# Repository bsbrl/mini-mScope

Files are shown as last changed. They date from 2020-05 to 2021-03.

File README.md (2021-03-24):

<p align="center">
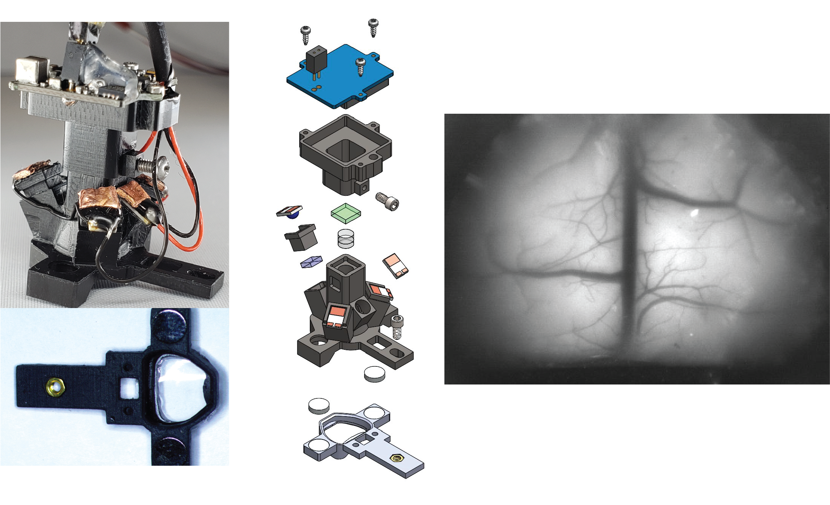
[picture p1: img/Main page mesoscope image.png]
  
</p>

Whole-cortex imaging in freely behaving mice using a head-mounted miniaturized microscope (mini-mScope). CMOS sensor sourced from the [Miniscope](https://github.com/Aharoni-Lab/Miniscope-v4/wiki).

The current version of the mini-mScope meets several experimental conditions highlighted below.

* Access to ~8x10 mm field of view of the mouse dorsal cortex
* Resolution ranges from ~39-56 micrometers across the field of view
* Weighs less than 15% of the mouse body weight (3.8 grams)
* Uniformly illuminates ~75% of the dorsal cortex with blue excitation light
* Green reflectance channel allows for hemodynamic correction ~65% of the field of view
* Does not impede mouse natural behavior (>1 hour mounting time with minimal effects on mouse traversed distance or speed)
* Posterior tail screw minimizes motion artifacts during vigorous, natural mouse behavior and during complex tasks, such as social interaction

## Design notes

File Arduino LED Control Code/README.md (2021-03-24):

Nested folders with the non-blocking functions used to alternately pulse the blue/green LEDs used for calcium/reflectance imaging.

We have also included code used for the sensory stimulus experiments performed on both anesthetized and freely moving mice

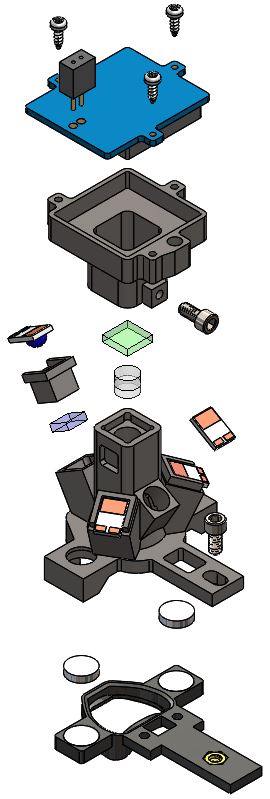
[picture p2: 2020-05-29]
Mesoscope CAD Files/Mesoscope Exploded View.JPG

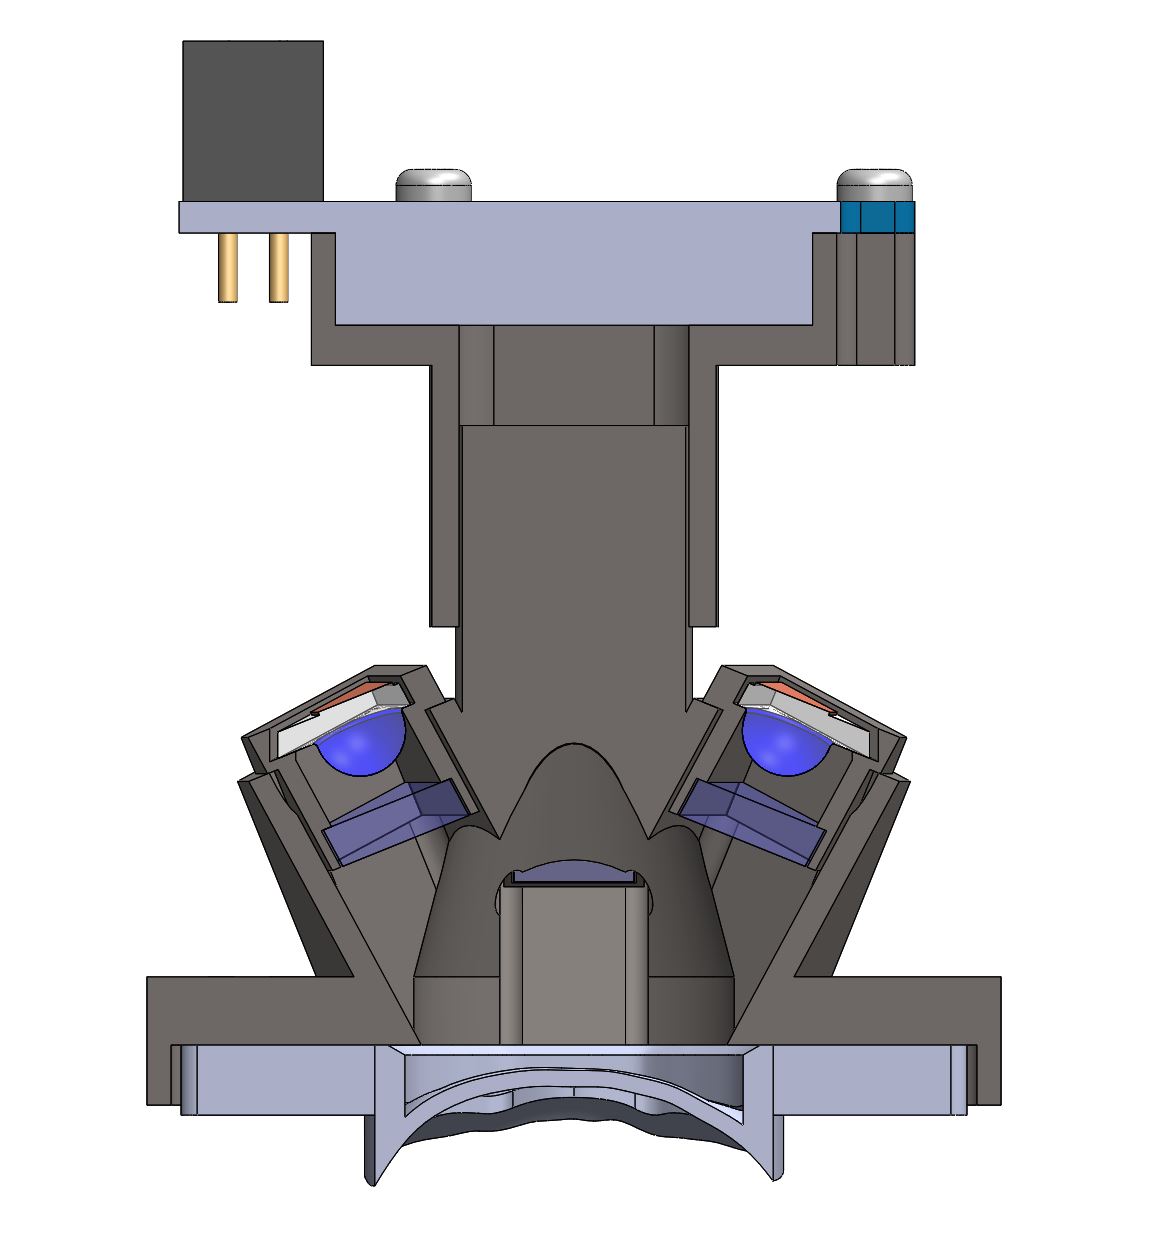
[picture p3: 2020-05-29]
Mesoscope CAD Files/Mesoscope Cross Section 2.JPG

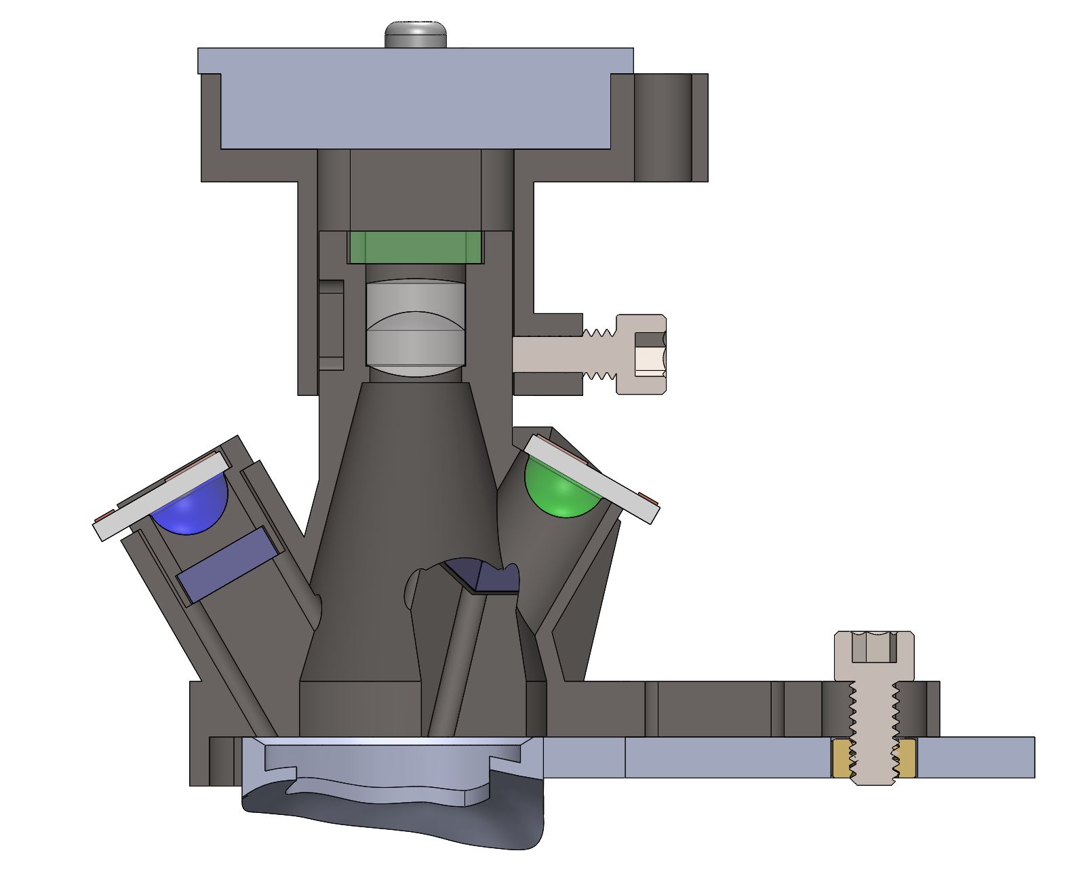
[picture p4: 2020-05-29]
Mesoscope CAD Files/Mesoscope Cross Section 1.JPG

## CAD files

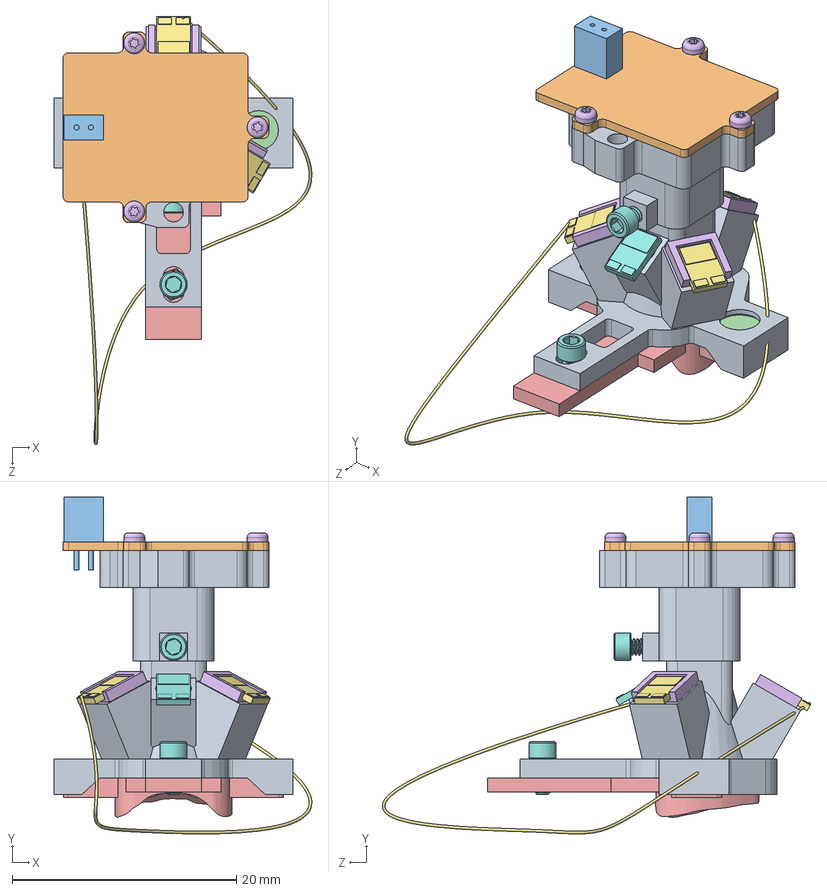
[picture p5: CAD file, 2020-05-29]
Mesoscope CAD Files/Mesoscope Assembly.SLDASM
23.0 x 30.0 x 38.2 mm
meso4.27_bottom_delrin
emmission_filter_4x4x1mm
excitation_filter_3x3x1mm x 3
filter_cube_ver5 x 3
excitation_led_rebel_blue_470nm x 3
excitation_led_rebel_green_530nm
meso4.22_top_delrin
CMOS_Imaging_Sensor_PCB
Pin Header Female
magnet x 4
082019_mesoscope_frame
thread_forming_screw x 3
92196A052_18-8 STAINLESS STEEL SOCKET HEAD CAP SCREW x 2
92736A001_BRASS HEX NUT

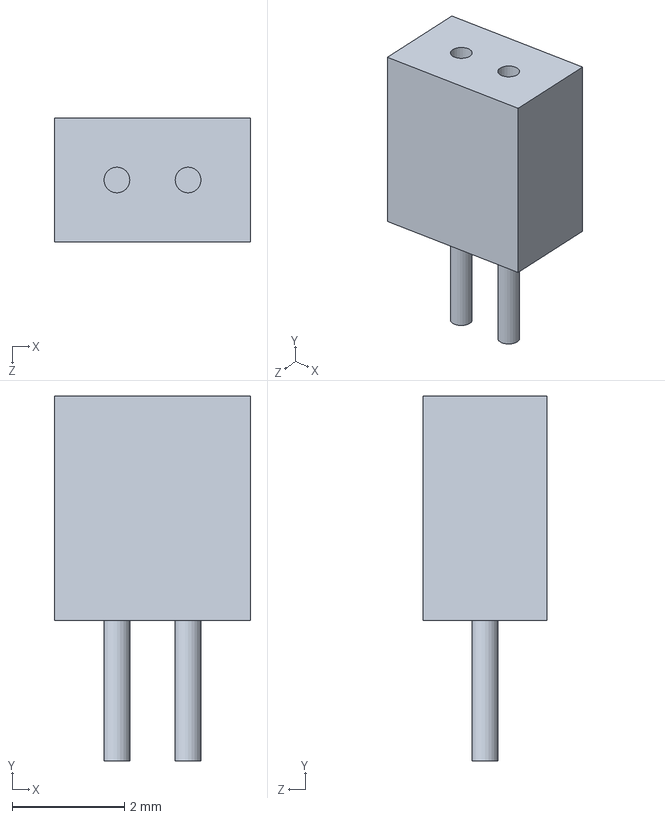
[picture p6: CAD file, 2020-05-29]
Mesoscope CAD Files/Pin Header Female.SLDPRT
3.50 x 6.51 x 2.21 mm

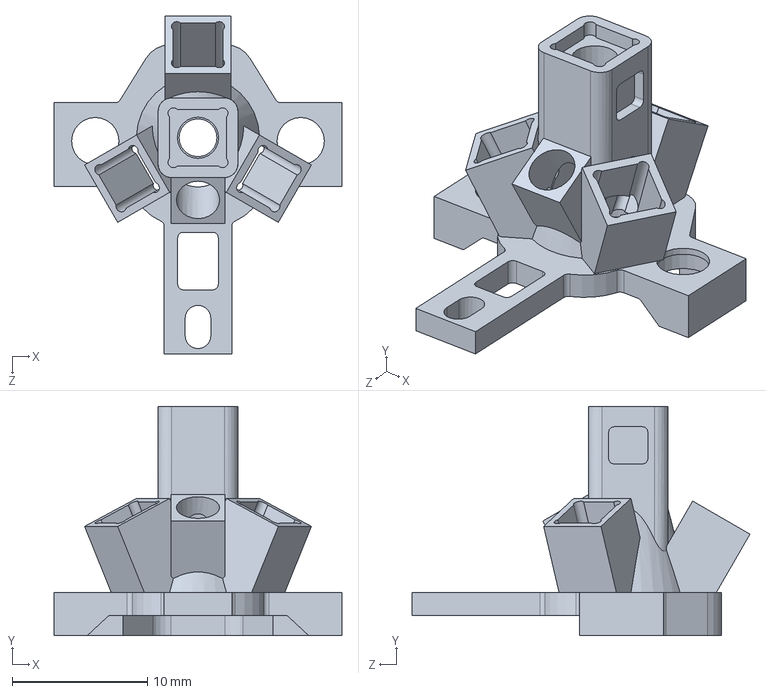
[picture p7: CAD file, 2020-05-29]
Mesoscope CAD Files/meso4.27_bottom_delrin.SLDPRT
21.3 x 17.0 x 25.0 mm

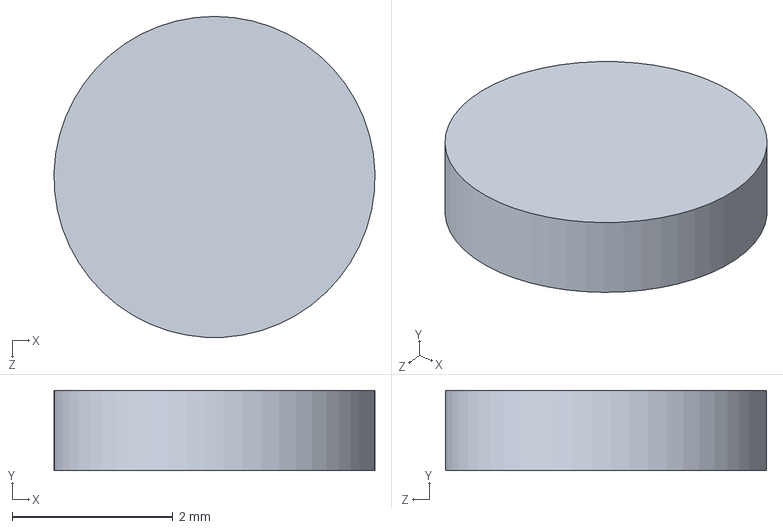
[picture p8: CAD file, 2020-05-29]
Mesoscope CAD Files/magnet.SLDPRT
4.00 x 1.00 x 4.00 mm

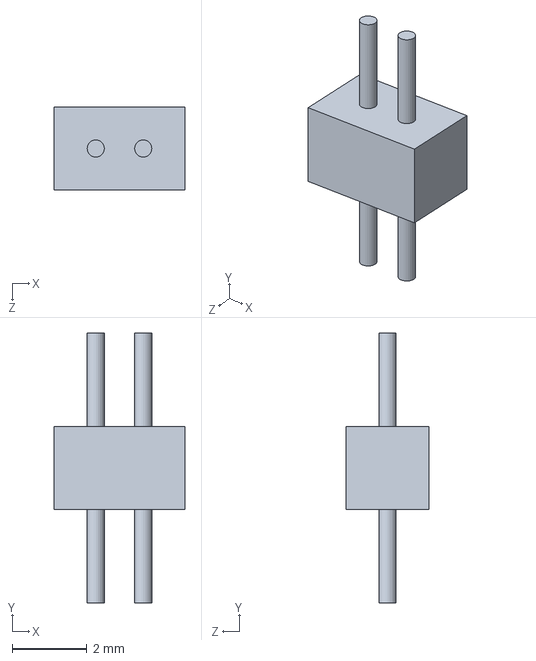
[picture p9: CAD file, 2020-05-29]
Mesoscope CAD Files/Pin Header male.SLDPRT
3.50 x 7.23 x 2.21 mm

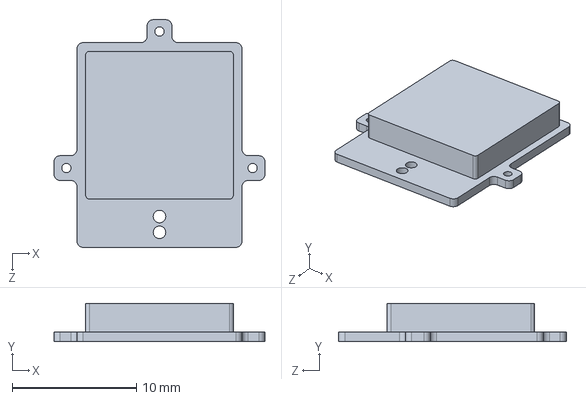
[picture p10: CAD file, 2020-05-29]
Mesoscope CAD Files/CMOS_Imaging_Sensor_PCB.SLDPRT
17.0 x 3.09 x 18.4 mm

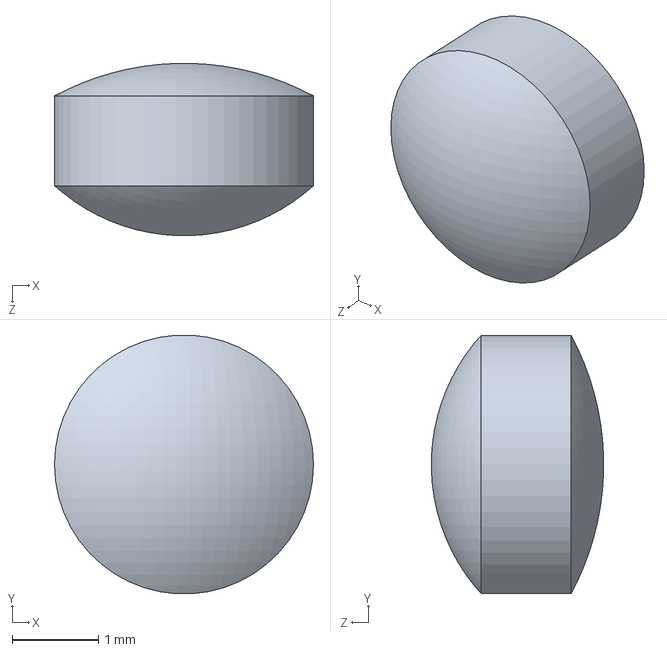
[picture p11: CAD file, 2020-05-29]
Mesoscope CAD Files/NONE (1).sldprt
3.00 x 2.99 x 1.99 mm

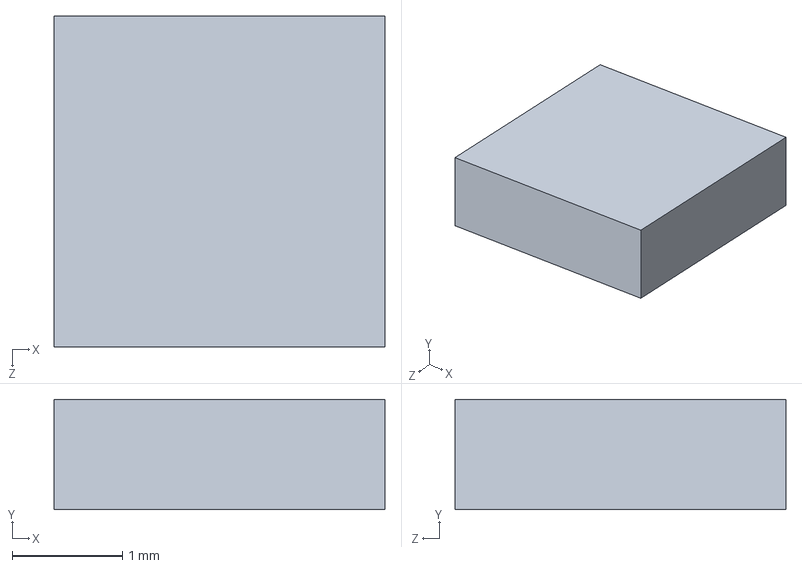
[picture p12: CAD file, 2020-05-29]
Mesoscope CAD Files/excitation_filter_3x3x1mm.SLDPRT
3.00 x 1.00 x 3.00 mm

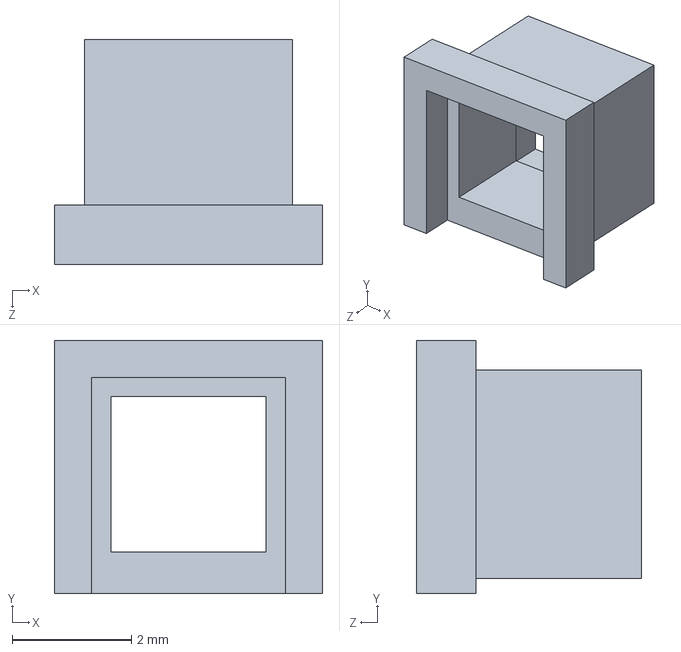
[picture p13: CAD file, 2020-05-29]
Mesoscope CAD Files/filter_cube_ver5.SLDPRT
4.50 x 4.25 x 3.78 mm

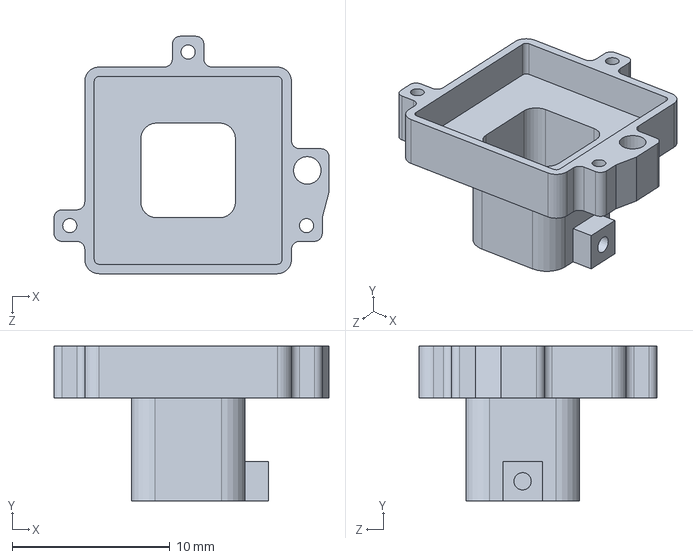
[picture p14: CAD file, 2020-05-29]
Mesoscope CAD Files/meso4.22_top_delrin.SLDPRT
17.4 x 9.82 x 15.1 mm

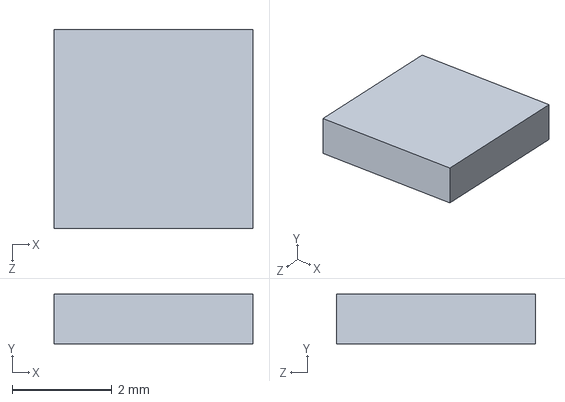
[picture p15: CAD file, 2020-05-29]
Mesoscope CAD Files/emmission_filter_4x4x1mm.SLDPRT
4.00 x 1.00 x 4.00 mm

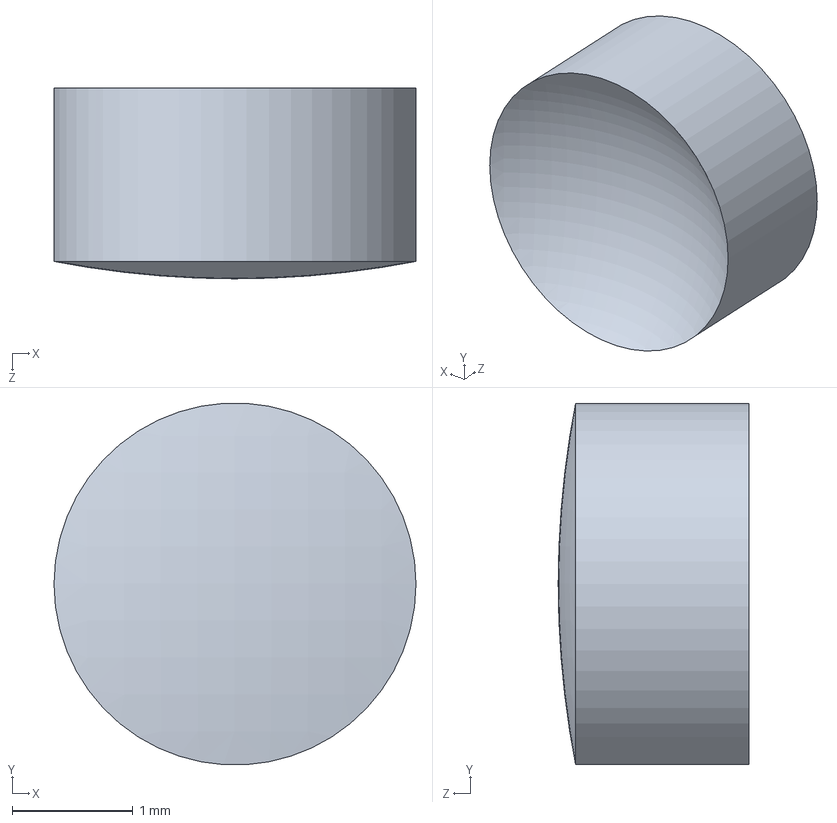
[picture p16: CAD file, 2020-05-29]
Mesoscope CAD Files/NONE_2 (2).sldprt
3.00 x 2.99 x 1.58 mm

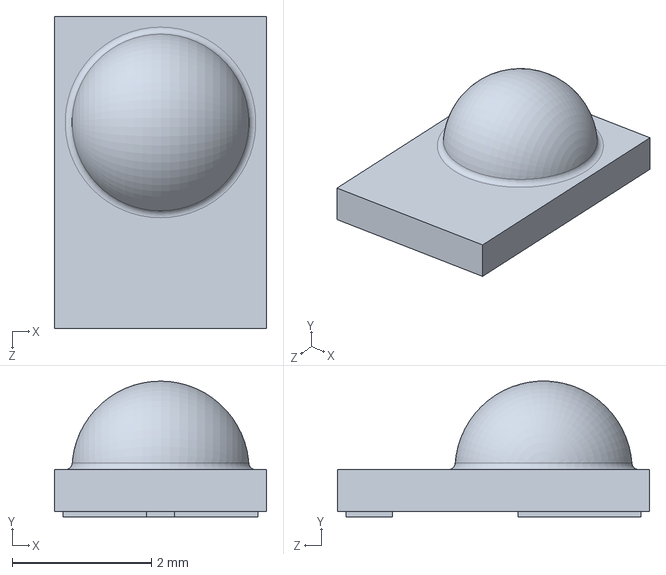
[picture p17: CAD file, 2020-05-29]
Mesoscope CAD Files/excitation_led_rebel_green_530nm.SLDPRT
3.05 x 1.95 x 4.49 mm

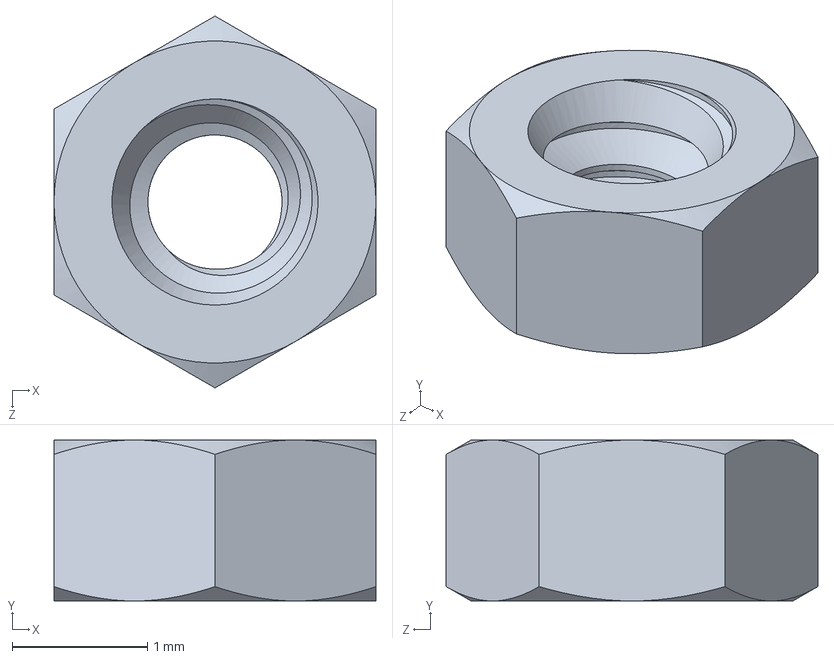
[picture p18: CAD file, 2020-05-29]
Mesoscope CAD Files/92736A001_BRASS HEX NUT.SLDPRT
2.38 x 1.19 x 2.75 mm

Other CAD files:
Mesoscope CAD Files/excitation_led_rebel_blue_470nm.SLDPRT
Mesoscope CAD Files/082019_mesoscope_frame.SLDPRT
Mesoscope CAD Files/thread_forming_screw.SLDPRT
Mesoscope CAD Files/92196A052_18-8 STAINLESS STEEL SOCKET HEAD CAP SCREW.SLDPRT

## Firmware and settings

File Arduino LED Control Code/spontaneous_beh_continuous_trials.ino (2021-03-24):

//-------------------------------User Defined Variables-------------------------------------------------------------------------------------------
const double blueled_time = 20; //led blinking interval in ms
const double greenled_time = 20; // green led blinking interval in ms
int totaltrials = 1; //total trials to run for specified experiment time
float exptime = 200; //data collection segment in seconds
float led_warmup_time = 120; //experimentally determined led warm up period in seconds

//notes
//1. LED pulse times have to be at least ~5ms less than the framerate set on the Miniscope camera (CMOS actual framerate may vary by +- ~5ms from set framerate)
//2. LED warmup time will add to the total experiment time for the first trial if there are more than 1 total trials set. This means if the experiment
//time is set 10 seconds per trial for 3 total trials, LED warmup time will run 120sec first before the first trial of 10 seconds. Then each subsequent
//trial will only last for the desired 10 seconds.
//3. For long experiment collection sections, you can simply change the total trials to 1 trial and set the experiment time to something less than 200 seconds
//as the total experiment time (LED warmup + exp_time*totaltrials) should be less than 350-400 seconds total to prevent LED  burnout.
//4. Note that at the end of each trial, the software will continue to record video so the LEDs maintain a constant temperature. The serial monitor
//will print the time at the end of each trial and these times can be passed to a script we can provide to auto-segment the video
//into individual trials if more than one trial duration has been set above



//-------------------------------Main Variables-------------------------------------------------------------------------------------------------------

const byte triggerin = 7; //trigger from controller to DAQ to start videos
const byte triggerout = 8; //ttl pulse from DAQ to controller when a frame is taken
const byte macroscope_trig = 2; //trig for external macroscope
unsigned long duration;

float globaltime;
float globaltime2;
float starttime;
float starttime2;
float previousMillis = 0; // will store last time LED was updated
float previousMillis2 = 0; // store last time buzzstim was updated


int count = 1;
int count2 = 1;
int totalloop = 1; // how many times to run through each stimulus pair
int incomingByte = 0;   // for incoming serial data

int testvar = 0;
const byte blueled = 3; // blue led at pin 3
const byte greenled = 10; // green led at pin 10


float ledtime; //time to turn on led before next trial starts (sec)

int ledState = HIGH;
int ledState2 = HIGH;
int pulsecount = 1;
int greencount = 1;
int bluecount = 1;
int buzzcount = 1;


float pulse_time = 5; //when to start pulse in seconds
float pulse_duration = 1; //pulse duration for stimulus in seconds
float pausetime = 0; //pause time between trials in seconds
float var;

float exptime_change = exptime;
float pulse_timechange = pulse_time;
//int trigdelay = 1;

int usercount = 1;
int val = 0;
int first_trigval = 0;
int blue_ledval = 0;
int green_ledval = 0;
int j;
int triggerwrite = 1;
int statementcount = 1;
int led_warmup_count = 1;
float temptime;


unsigned long temp;
unsigned long temp2;

volatile byte state = LOW;

void setup() {
  // put your setup code here, to run once:
  pinMode(triggerin, OUTPUT);
  pinMode(triggerout, INPUT);
  pinMode(blueled, OUTPUT);
  pinMode(greenled, OUTPUT);
  pinMode(macroscope_trig, OUTPUT);
  attachInterrupt(digitalPinToInterrupt(triggerout), PulseLed, CHANGE);
  Serial.begin(19200);

  //Serial.println("Enter any key to begin the program");
}

void loop() {
  if (testvar == 0) {
    incomingByte = Serial.read();
    usercount += 1;
    if (usercount % 100000 == 0) {
      Serial.println("Pending user input... enter y to begin ");
      //Serial.println(interval*1000);
    }

    if (incomingByte != -1) { //if user input is non zero
      testvar = 1;
      //Serial.println(usercount);
    }
  }


  if (testvar == 1) {
    if (totalloop <= totaltrials) {
      starttime2 = micros();
      if (triggerwrite == 1) {
        digitalWrite(triggerin, HIGH); // trigger DAQ to start recording

        triggerwrite = 2;
      }

      if (count == 1) { // take first instance after trigger sent and record this ttl value
        first_trigval = state;
        count = 2;
      }

      if (count == 2) {
        if (state != first_trigval) { //take first instance where the ttl pulse value changes
          Serial.println(" ");
          Serial.println("Starting video now: ");
          Serial.println(" ");

          globaltime = micros(); // take teensy clock
          starttime = globaltime;
          globaltime2 = globaltime;
          count = 3;
          //Serial.print("current val ");
          //Serial.print(val);
          //Serial.println(" ");
          blue_ledval = state; //assign first different value to be blue led (assume first bright frame captured to be blue led)
          green_ledval = first_trigval; //assign 0 state ttl pulse to be green led

          //Serial.println(blue_ledval);
          //Serial.println(green_ledval);
        }
      }
      if (totalloop == 1) {
        pulse_timechange = pulse_time + led_warmup_time;
        exptime_change = exptime + led_warmup_time;
      }

      if (count == 3) {
        if (starttime <= (exptime_change + globaltime / 1000000) * 1000000) { //run led pulsing for experiment duration
          if (led_warmup_count == 1) {
            if (starttime >= (led_warmup_time + globaltime / 1000000) * 1000000) {
              //digitalWrite(macroscope_trig,HIGH);
              Serial.print("LEDs warmed up");
              Serial.println(" ");
              Serial.print("Current time is ");
              if (totalloop == 1) {
                temptime = (starttime - globaltime) / 1000;
              } else {
                temptime = (starttime - globaltime2) / 1000;
              }

              Serial.print(temptime);
              Serial.println(" milliseconds");
              Serial.println(" ");
              led_warmup_count = 2;
            }
          }
          float currentMillis = micros();
          starttime = currentMillis;
          statementcount = 1;
          if (blue_ledval == state) { //if blue led ttl is equal to current read ttl value

            if (bluecount == 1) { // if "on" counter for blue led is true
              previousMillis = currentMillis;
              digitalWrite(blueled, HIGH); //turn blue led on
              digitalWrite(macroscope_trig, HIGH);
              //ledState = LOW;//switch led state
              bluecount = 2; //change counter to "off" for blueu led
            }
            if (currentMillis - previousMillis >= blueled_time * 1000) { //if time grows beyond desired for blue led pulse
              digitalWrite(blueled, LOW); //turn led off
              digitalWrite(macroscope_trig, LOW);
              greencount = 1; //assume a switch to green led now
              //ledState2 = HIGH;
            }
          } else { //run when ttl value changes (i.e. switch from green to blue)

            if (greencount == 1) {

              previousMillis = currentMillis; //repeat above with green led
              digitalWrite(greenled, HIGH);
              digitalWrite(macroscope_trig, HIGH);
              //ledState2 = LOW;
              greencount = 2;

            }
            if (currentMillis - previousMillis >= blueled_time * 1000) {
              digitalWrite(greenled, LOW);
              digitalWrite(macroscope_trig, LOW);
              bluecount = 1;
              //ledState = HIGH;
            }
          }
        } else {
          //            for (j=1;j<=1000;j++){
          //              digitalWrite(triggerin,LOW);
          //            }

          //digitalWrite(triggerin,LOW);
          if (statementcount == 1) {
            Serial.print("End of Trial ");
            Serial.println(totalloop);
            Serial.print("Current time is ");
            if (totalloop == 1) {
              temptime = (starttime - globaltime) / 1000;
            } else {
              temptime = (starttime - globaltime2) / 1000;
            }
            Serial.print(temptime);
            Serial.println(" milliseconds");
            Serial.println(" ");
            //digitalWrite(greenled,LOW);
            //digitalWrite(blueled,LOW);
            statementcount = 2;
          }


          if (starttime <= (exptime_change + pausetime + globaltime / 1000000) * 1000000) {
            starttime = micros();
          } else {
            if (count2 == 1) {
              starttime2 = micros();
              count2 = 2;
              ledtime = starttime2 + 0;//10000;
            }
            if ( starttime <= ledtime ) {
              starttime = micros();
            } else {
              //digitalWrite(ledpin,LOW);
              starttime = micros();
              exptime_change = starttime / 1000000 + exptime;
              pulse_timechange = starttime / 1000000 + pulse_time;
              globaltime = 0;


              totalloop += 1;
              triggerwrite = 1;
              count2 = 1;
            }
            //              starttime = micros();
            //              exptime_change = starttime/1000000 + exptime;
            //              pulse_timechange = starttime/1000000 + pulse_time;
            globaltime = 0;
            starttime = micros();
            //
            //
            //              totalloop += 1;
            //              triggerwrite = 1;
          }

        }
      }
    } else { //if outside experiment time
      if (totalloop == totaltrials + 1) {
        Serial.println("Experiment has concluded");
        digitalWrite(blueled, LOW); //shut down leds and conclude experiment
        digitalWrite(greenled, LOW);
        digitalWrite(triggerin, LOW);
        digitalWrite(macroscope_trig, LOW);
        totalloop += 1;
        testvar = 2;
      }
    }
  }
}



void PulseLed() {
  state = digitalRead(triggerout);
  digitalWrite(macroscope_trig, LOW);
  //delayMicroseconds(2000);
}

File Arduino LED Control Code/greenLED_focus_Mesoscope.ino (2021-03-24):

int i=0;
char buf[3];
int ledpin = 9;

void setup()
{
   Serial.begin(19200);
   pinMode(ledpin,OUTPUT);
}

void loop()
{
  if (Serial.available()>0){
   
   
    buf[i]= Serial.read();
   
    if (int(buf[i])==13 || int(buf[i])==11 ){  //If Carriage return has been reached
     
      int result=atoi(buf);
      Serial.print("PWM ");   
      Serial.println(result);     //print the converted char ar
      analogWrite(ledpin,result);
      if(result>255){
      Serial.println("Warning number too big");
      }
       
    for(int x=0;x<=3;x++){
    buf[x]=' ';
    }
    i=0;  //start over again
    } //if enter
     i++;
    } //IF Serial.available
 
 

}//LOOP
